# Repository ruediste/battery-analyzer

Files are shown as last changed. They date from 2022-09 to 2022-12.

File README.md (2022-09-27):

# battery-analyzer
Open Source battery analyzer

# Resistor Matching
When building your channel boards, make sure to match the resistors. See `firmware/src/resistorMatcher.cpp` for details.

# Calibration

1. Calibrate Voltage: connect a PSU to the plus pole of the battery, apply about 4.2V. Measure the voltage and enter it.
1. Zero PWM:

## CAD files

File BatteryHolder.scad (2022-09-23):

// Distance between the cell centers. 35mm allow you to easily grab the cells.
period=35;

// Diameter of the battery
batteryDiameter=18;

// number of holder units
units=4;

// add slides for the battery plate/slide 
plateSlide=false;

// add a hole to use a screw to connect to the battery terminals
screw=false;

/* Hidden */
$fn=10;
module mountingUnit(){
    //translate([0,0,0]) rotate([-90,0,0]) cylinder(h=65.0,d=18);
    translate([0,-5,0]) difference() {
        union(){
            translate([0,-25/2,0]) cube([period+2.51,25,20], center=true);
            
            // plateSlide holder
            if (plateSlide) translate([0,0.99,0]) cube([14.5,2,20], center=true);
        }
        
        translate([0,-30.01/2,2]) cube([period-2.5,20,20], center=true);
        
        if (screw){
        // hex
        translate([0,-3,0]) rotate([-90,0,0]) cylinder(h=4, d=6.35, $fn=6);
        
        // screw hole
        translate([0,-6,0]) rotate([-90,0,0]) cylinder(h=7, d=3.5);
        
        // wire hole
        translate([period/2-4,-6,0]) rotate([-90,0,0]) cylinder(h=7, d=3.5);
               
        // wire opening
        translate([period/4-2,0.5,0]) cube([period/2,3,3.5], center=true);
        }
        
        // 45 deg sides
        translate([0,-22,10]) rotate([45,0,0]) cube([period+7,40,20], center=true);
        
        // mounting slot
        translate([0,-18,-15]) rotate([0,0,0]) cylinder(h=20, d=5);
        translate([0,-12,-15]) rotate([0,0,0]) cylinder(h=20, d=5);
        translate([-2.5,-18,-15]) cube([5,6,10]);
        
        if (plateSlide){
            // plateSlide slide
            translate([0,0.49,4.5-10]) cube([10.5,1,20], center=true);
            
            // plateSlide middle
            translate([0,1.49,0]) cube([7.5,3,25], center=true);
        } else {
            // plateSlide position
            if (!screw) translate([0,0,1]) cube([11,1,12], center=true);
        }
        
        // plateSlide lead
        translate([0,-4,14.5]) cube([4,10,20], center=true);
        
        // reduce height
        translate([-period/2-5,-15,5.5]) cube([period+10,20,20]);

    }
}
for (i=[1:units]){
    translate([(period)*(i-1),0,0])    mountingUnit();
}

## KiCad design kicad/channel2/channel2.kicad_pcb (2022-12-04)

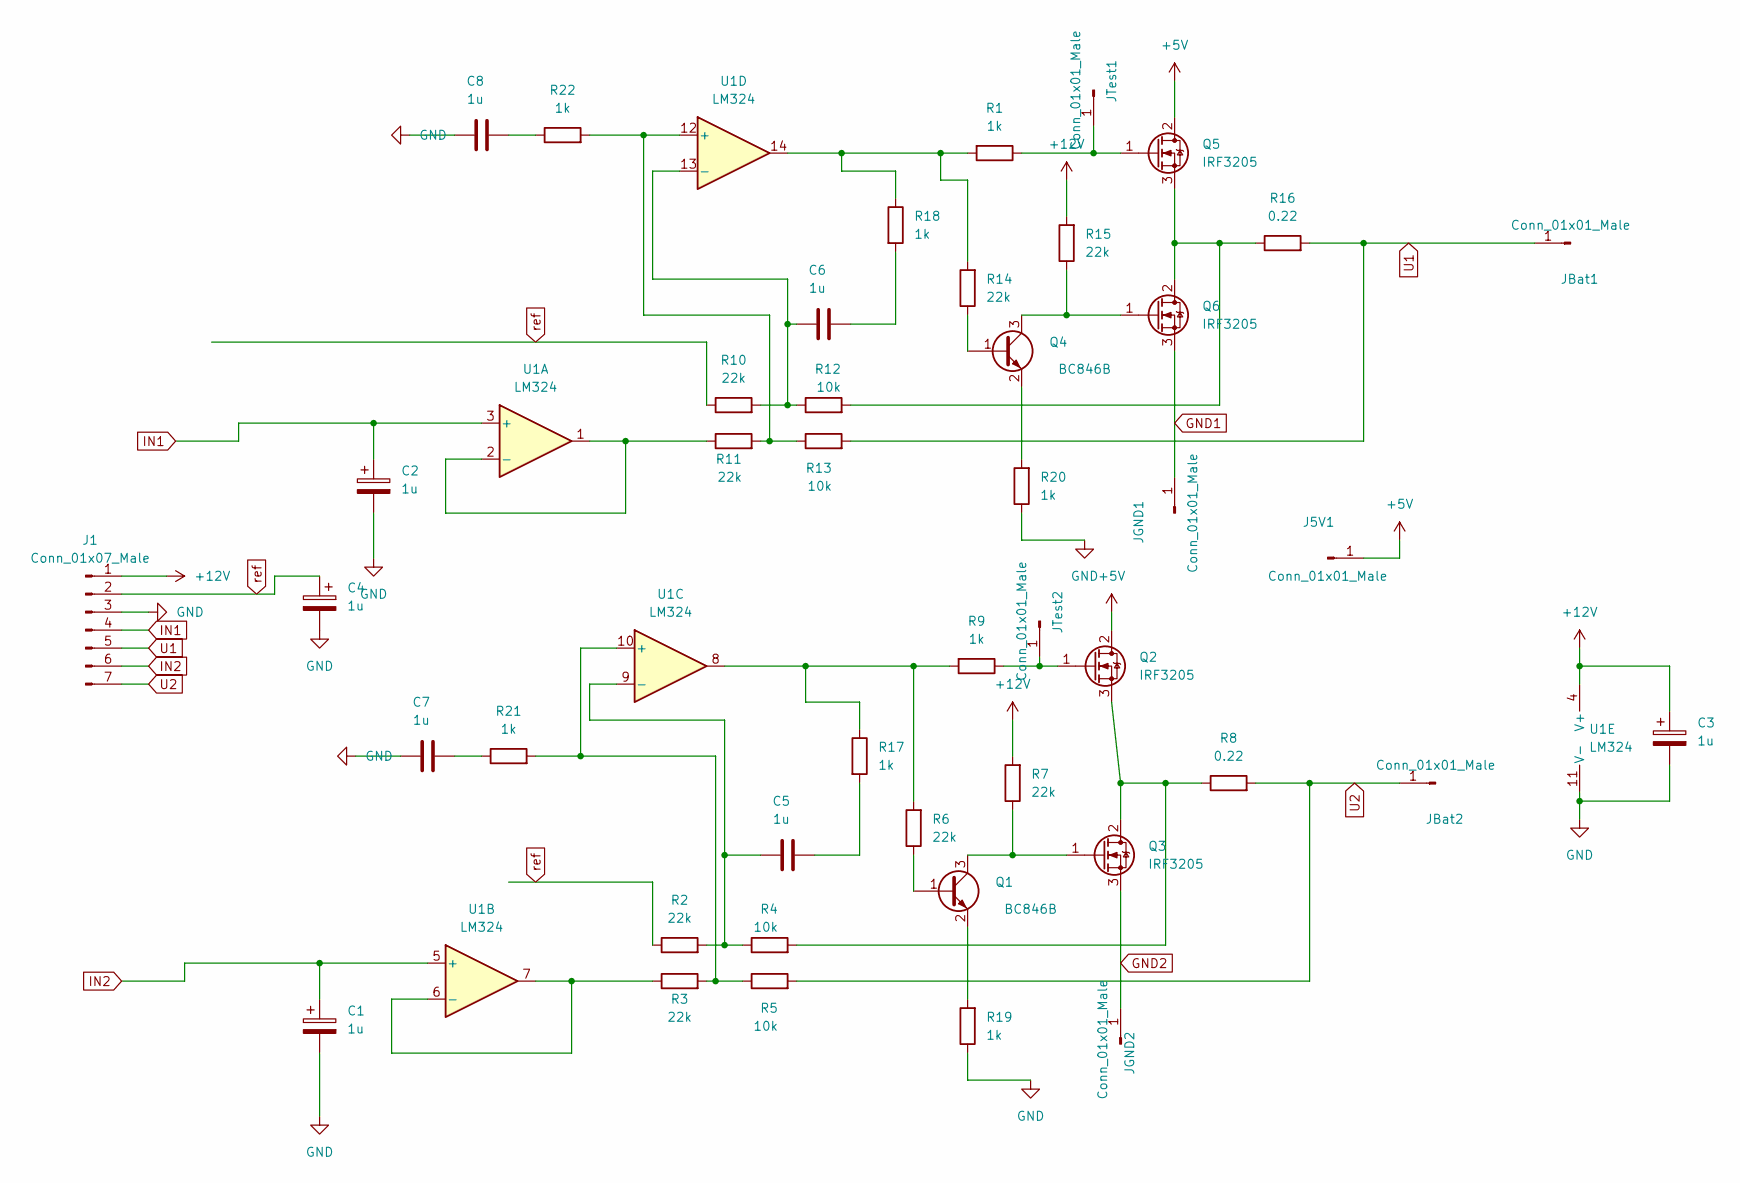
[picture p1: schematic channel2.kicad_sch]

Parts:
C1, C2, C3, C4, C5, C6, C7, C8: 1u; C_0603_1608Metric
J1: Conn_01x07_Male; PinHeader_1x07_P2.54mm_Vertical
J5V1: Conn_01x01_Male; PowerPad
JBat1, JBat2: Conn_01x01_Male; PowerPad
JGND1, JGND2: Conn_01x01_Male; PowerPad
JTest1, JTest2: Conn_01x01_Male; PinHeader_1x01_P2.54mm_Vertical
Q1, Q4: BC846B; SOT-23
Q2, Q3, Q5, Q6: IRF3205; TO-220-3_Vertical
R1, R9, R17, R18, R19, R20, R21, R22: 1k; R_1206_3216Metric
R2, R3, R6, R7, R10, R11, R14, R15: 22k; R_1206_3216Metric
R4, R5, R12, R13: 10k; R_1206_3216Metric
R8, R16: 0.22; R_Axial_DIN0617_L17.0mm_D6.0mm_P25.40mm_Horizontal
U1: LM324; SOIC-14_3.9x8.7mm_P1.27mm

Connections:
+5V: J5V1.1, Q2.2 (D), Q5.2 (D)
+12V: C3.1, J1.1, R7.2, R15.2, U1.4 (V+)
GND: C1.2, C2.2, C3.2, C4.2, C7.1, C8.1, J1.3, R19.1, R20.1, U1.11 (V-)
GND1: JGND1.1, Q6.3 (S)
GND2: JGND2.1, Q3.3 (S)
IN1: C2.1, J1.4, U1.3 (+)
IN2: C1.1, J1.6, U1.5 (+)
unnamed: C5.1, R2.2, R4.1, U1.9 (-)
unnamed: C5.2, R17.2
unnamed: C6.1, R10.2, R12.1, U1.13 (-)
unnamed: C6.2, R18.2
unnamed: C7.2, R21.1
unnamed: C8.2, R22.1
unnamed: JTest1.1, Q5.1 (G), R1.1
unnamed: JTest2.1, Q2.1 (G), R9.1
unnamed: Q1.1 (B), R6.1
unnamed: Q1.2 (E), R19.2
unnamed: Q1.3 (C), Q3.1 (G), R7.1
unnamed: Q2.3 (S), Q3.2 (D), R4.2, R8.1
unnamed: Q4.1 (B), R14.1
unnamed: Q4.2 (E), R20.2
unnamed: Q4.3 (C), Q6.1 (G), R15.1
unnamed: Q5.3 (S), Q6.2 (D), R12.2, R16.1
unnamed: R1.2, R14.2, R18.1, U1.14
unnamed: R3.1, U1.6 (-), U1.7
unnamed: R11.1, U1.1, U1.2 (-)
unnamed: R11.2, R13.1, R22.2, U1.12 (+)
unnamed: R6.2, R9.2, R17.1, U1.8
unnamed: R3.2, R5.1, R21.2, U1.10 (+)
U1: J1.5, JBat1.1, R13.2, R16.2
U2: J1.7, JBat2.1, R5.2, R8.2
ref: C4.1, J1.2, R2.1, R10.1

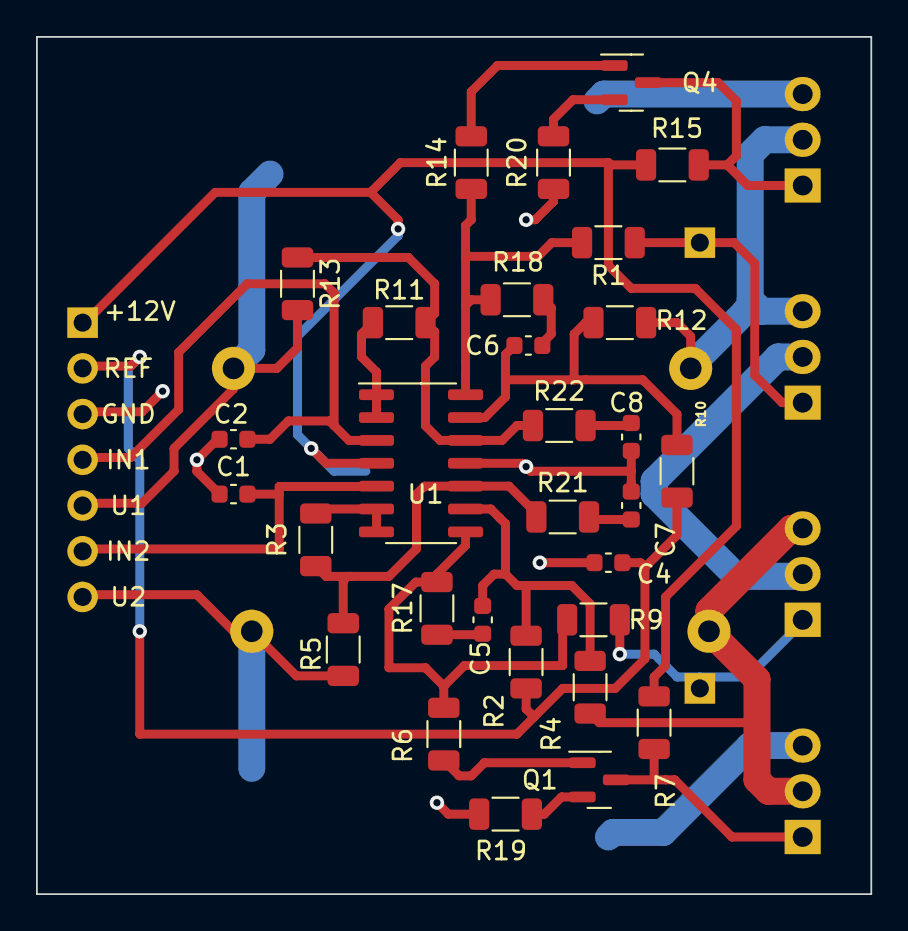
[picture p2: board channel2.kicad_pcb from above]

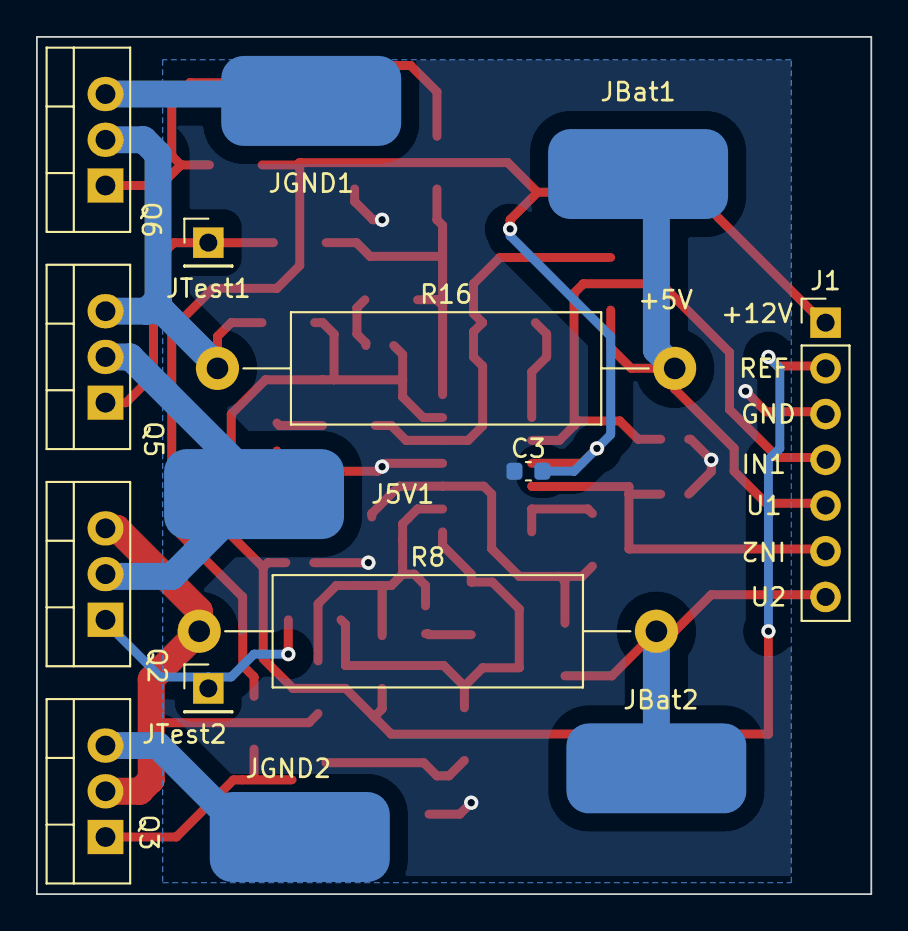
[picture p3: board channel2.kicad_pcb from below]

Board: 2 copper layers, 46.4 x 47.6 mm, 45 parts (15 on the bottom side), 32 nets.

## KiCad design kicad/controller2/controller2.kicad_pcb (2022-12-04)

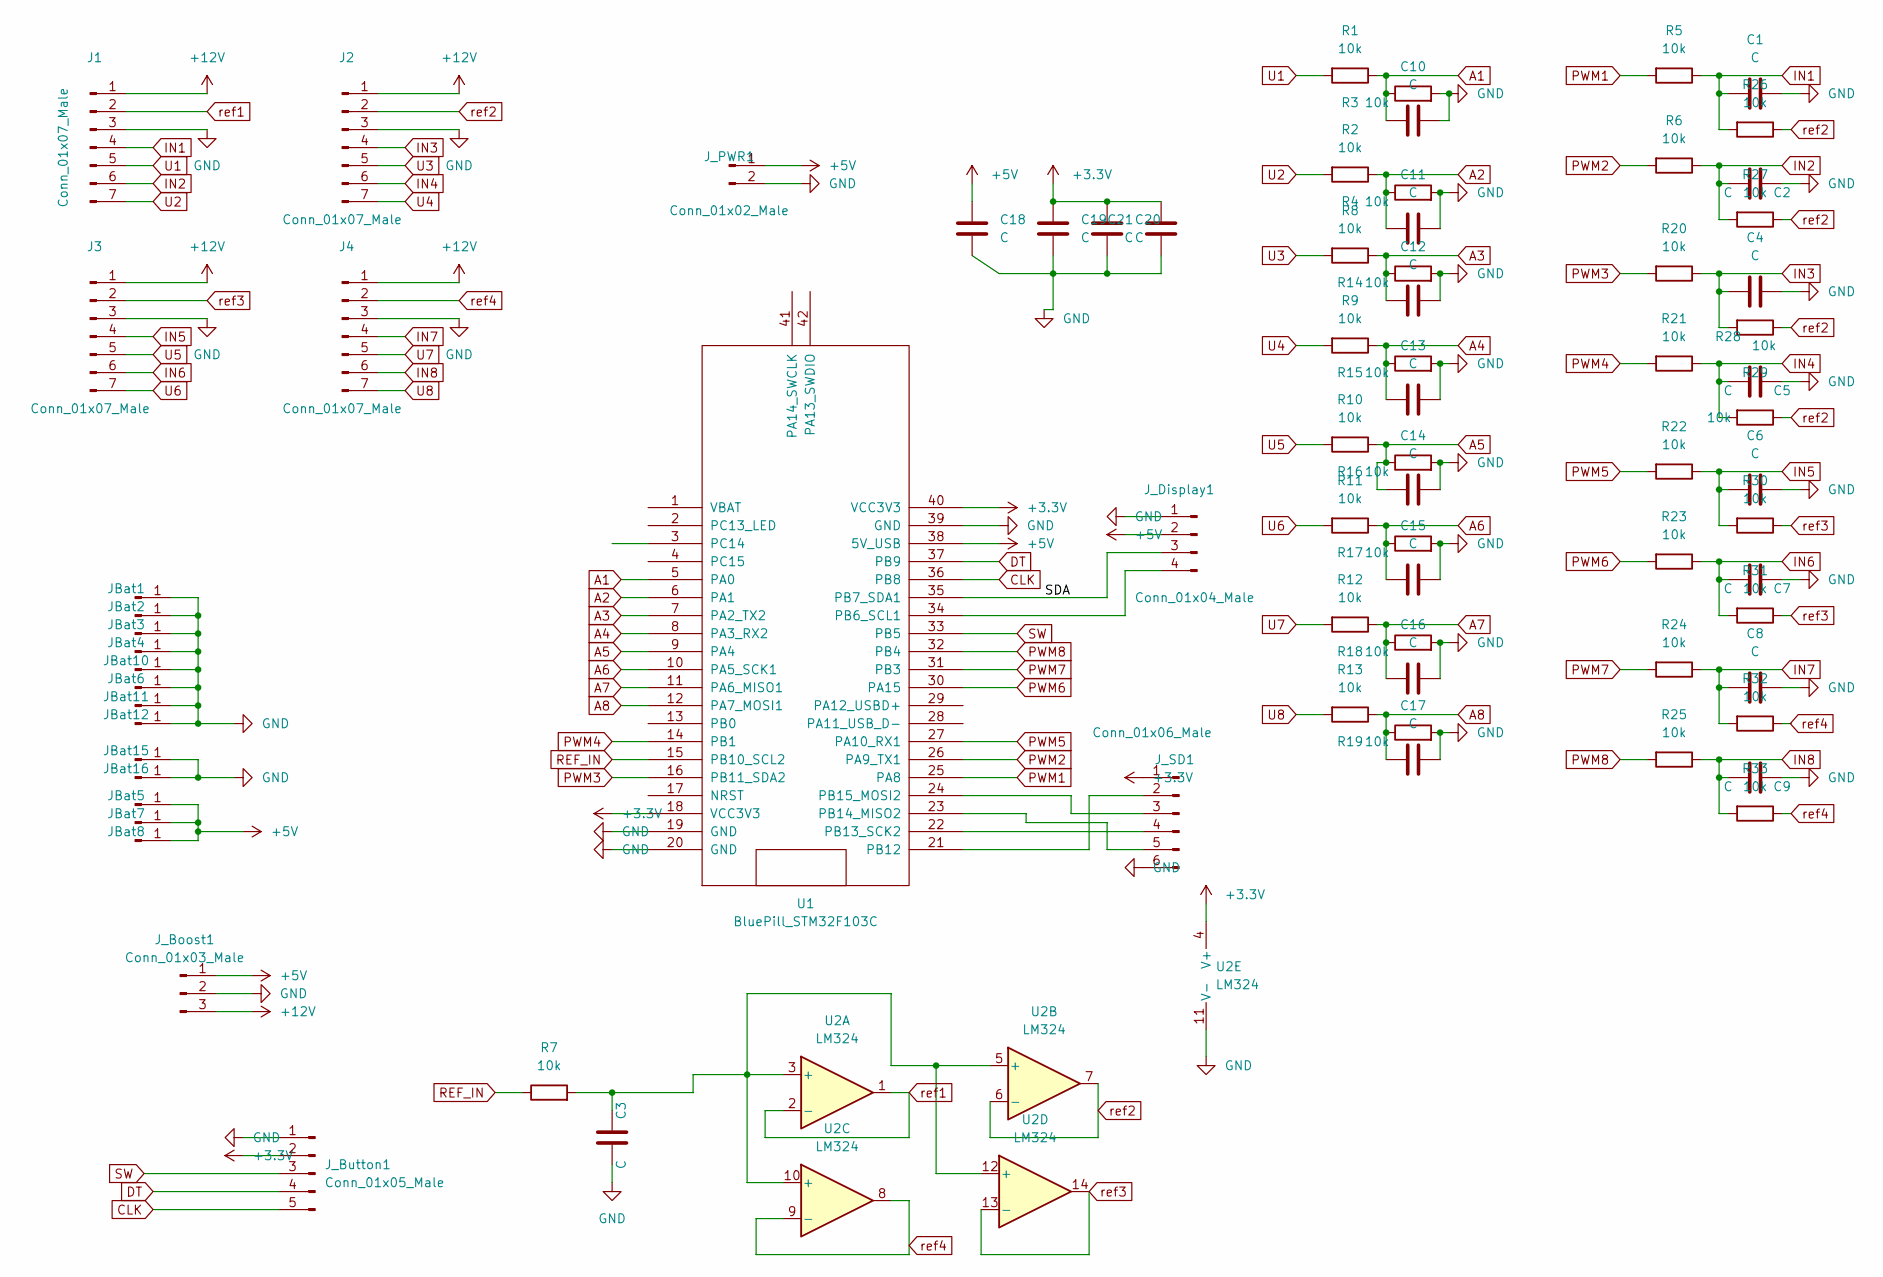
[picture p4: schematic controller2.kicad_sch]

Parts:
C1, C2, C3, C4, C5, C6, C7, C8, C9, C10, C11, C12, C13, C14, C15, C16, C17, C18, C19, C20, C21: C; C_0805_2012Metric
J1, J2, J3, J4: Conn_01x07_Male; PinHeader_1x07_P2.54mm_Vertical
JBat1, JBat2, JBat3, JBat4, JBat5, JBat6, JBat7, JBat8, JBat10, JBat11, JBat12, JBat15, JBat16: Conn_01x01_Male; PowerPin
J_Boost1: Conn_01x03_Male; PinHeader_1x03_P2.54mm_Vertical
J_Button1: Conn_01x05_Male; PinHeader_1x05_P2.54mm_Vertical
J_Display1: Conn_01x04_Male; PinHeader_1x04_P2.54mm_Vertical
J_PWR1: Conn_01x02_Male; PinHeader_1x02_P2.54mm_Vertical
J_SD1: Conn_01x06_Male; SD_Card_reader
R1, R2, R3, R4, R5, R6, R7, R8, R9, R10, R11, R12, R13, R14, R15, R16, R17, R18, R19, R20, R21, R22, R23, R24, R25, R26, R27, R28, R29, R30, R31, R32, R33: 10k; R_1206_3216Metric
U1: BluePill_STM32F103C; BluePill
U2: LM324; SOIC-14_3.9x8.7mm_P1.27mm

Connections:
+3.3V: C19.2, C20.2, C21.2, J_Button1.2, J_SD1.1, U1.18 (VCC3V3), U1.40 (VCC3V3), U2.4 (V+)
+5V: C18.2, JBat5.1, JBat7.1, JBat8.1, J_Boost1.1, J_Display1.2, J_PWR1.1, U1.38 (5V_USB)
+12V: J1.1, J2.1, J3.1, J4.1, J_Boost1.3
/SDA: J_Display1.3, U1.35 (PB7_SDA1)
A1: C10.1, R1.1, R3.1, U1.5 (PA0)
A2: C11.1, R2.1, R4.1, U1.6 (PA1)
A3: C12.1, R8.1, R14.1, U1.7 (PA2_TX2)
A4: C13.1, R9.1, R15.1, U1.8 (PA3_RX2)
A5: C14.1, R10.1, R16.1, U1.9 (PA4)
A6: C15.1, R11.1, R17.1, U1.10 (PA5_SCK1)
A7: C16.1, R12.1, R18.1, U1.11 (PA6_MISO1)
A8: C17.1, R13.1, R19.1, U1.12 (PA7_MOSI1)
CLK: J_Button1.5, U1.36 (PB8)
DT: J_Button1.4, U1.37 (PB9)
GND: C1.2, C2.2, C3.1, C4.2, C5.2, C6.2, C7.2, C8.2, C9.2, C10.2, C11.2, C12.2, C13.2, C14.2, C15.2, C16.2, C17.2, C18.1, C19.1, C20.1, C21.1, J1.3, J2.3, J3.3, J4.3, JBat1.1, JBat2.1, JBat3.1, JBat4.1, JBat6.1, JBat10.1, JBat11.1, JBat12.1, JBat15.1, JBat16.1, J_Boost1.2, J_Button1.1, J_Display1.1, J_PWR1.2, J_SD1.6, R3.2, R4.2, R14.2, R15.2, R16.2, R17.2, R18.2, R19.2, U1.19 (GND), U1.20 (GND), U1.39 (GND), U2.11 (V-)
IN1: C1.1, J1.4, R5.1, R26.2
IN2: C2.1, J1.6, R6.1, R27.2
IN3: C4.1, J2.4, R20.1, R28.2
IN4: C5.1, J2.6, R21.1, R29.2
IN5: C6.1, J3.4, R22.1, R30.2
IN6: C7.1, J3.6, R23.1, R31.2
IN7: C8.1, J4.4, R24.1, R32.2
IN8: C9.1, J4.6, R25.1, R33.2
unnamed: C3.2, R7.2, U2.3 (+), U2.5 (+), U2.10 (+), U2.12 (+)
unnamed: J_Display1.4, U1.34 (PB6_SCL1)
unnamed: J_SD1.2, U1.21 (PB12)
unnamed: J_SD1.3, U1.24 (PB15_MOSI2)
unnamed: J_SD1.4, U1.22 (PB13_SCK2)
unnamed: J_SD1.5, U1.23 (PB14_MISO2)
PWM1: R5.2, U1.25 (PA8)
PWM2: R6.2, U1.26 (PA9_TX1)
PWM3: R20.2, U1.16 (PB11_SDA2)
PWM4: R21.2, U1.14 (PB1)
PWM5: R22.2, U1.27 (PA10_RX1)
PWM6: R23.2, U1.30 (PA15)
PWM7: R24.2, U1.31 (PB3)
PWM8: R25.2, U1.32 (PB4)
REF_IN: R7.1, U1.15 (PB10_SCL2)
SW: J_Button1.3, U1.33 (PB5)
U1: J1.5, R1.2
U2: J1.7, R2.2
U3: J2.5, R8.2
U4: J2.7, R9.2
U5: J3.5, R10.2
U6: J3.7, R11.2
U7: J4.5, R12.2
U8: J4.7, R13.2
ref1: J1.2, U2.1, U2.2 (-)
ref2: J2.2, R26.1, R27.1, R28.1, R29.1, U2.6 (-), U2.7
ref3: J3.2, R30.1, R31.1, U2.13 (-), U2.14
ref4: J4.2, R32.1, R33.1, U2.8, U2.9 (-)

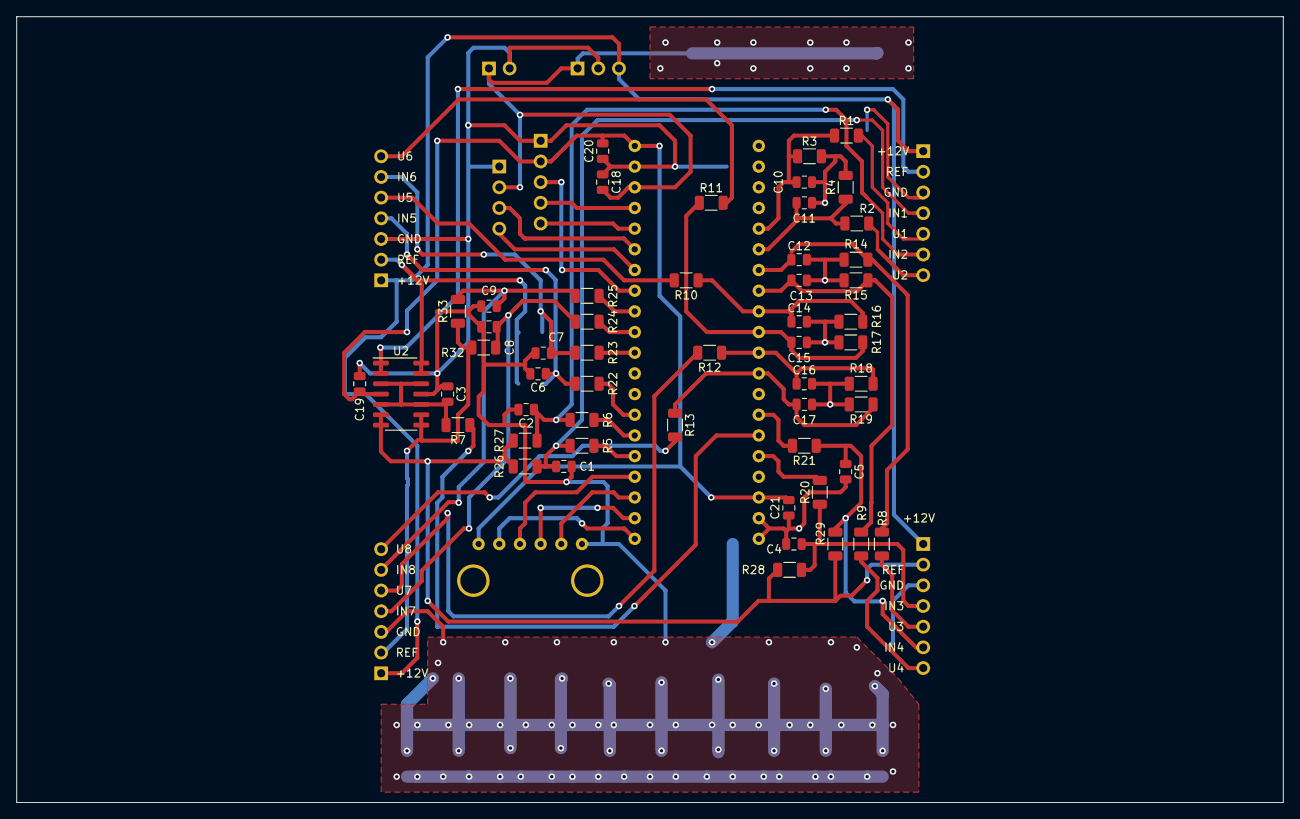
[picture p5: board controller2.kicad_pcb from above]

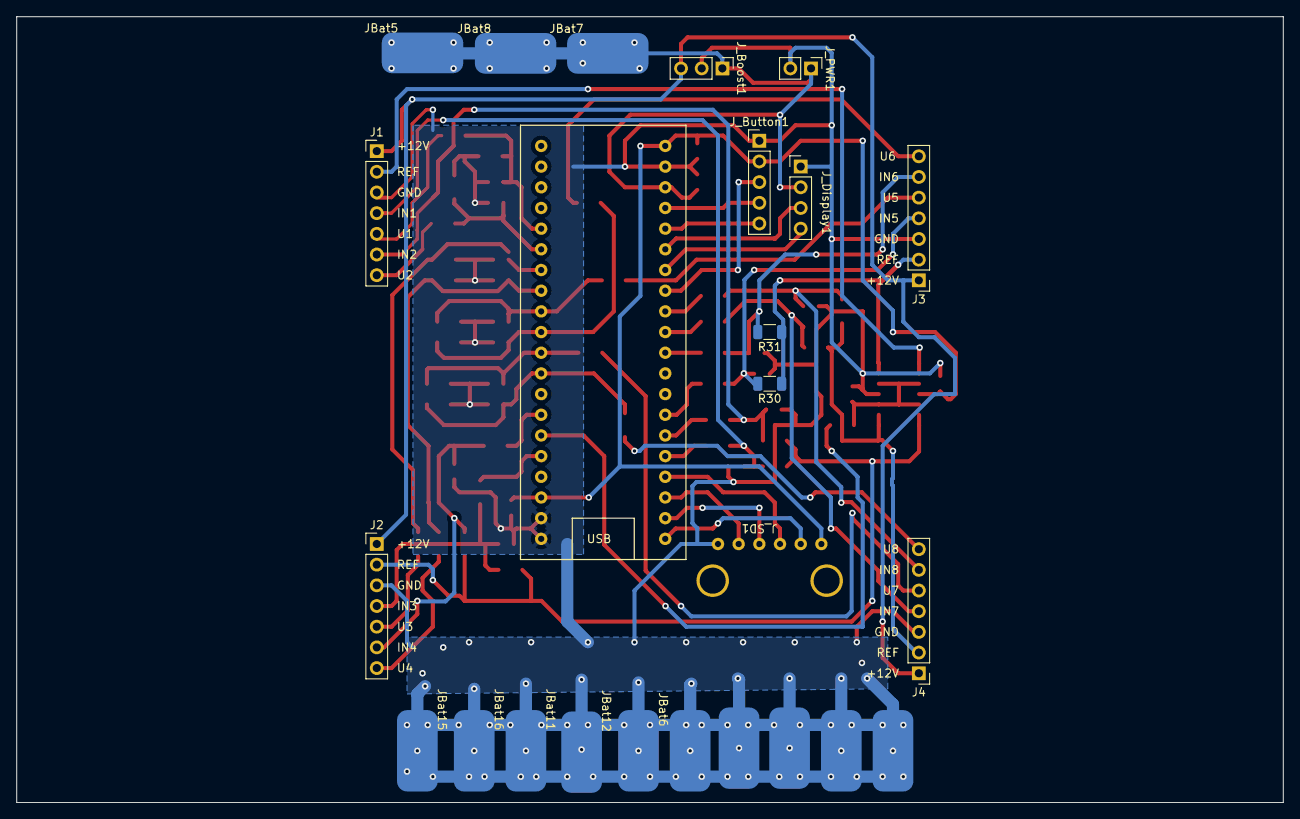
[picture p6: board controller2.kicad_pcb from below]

Board: 2 copper layers, 155.6 x 96.5 mm, 78 parts (25 on the bottom side), 51 nets.

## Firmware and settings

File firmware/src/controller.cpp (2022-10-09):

#include "controller.h"
#include "menu.h"
#include "display.h"
#include "types.h"
#include "input.h"
#include "batteryChannel.h"
#include "utils.h"
#include "numberInput.h"
#include "eeprom.h"
#include "sdLogging.h"
#include "messageDisplay.h"
#include "log.h"

namespace controller
{
    int _currentChannel = 0;

    bool showStatistics = false;
    int statisticsPage = 0;
    int maxStatisticsPage = 1;

    instantMs_t lastDisplayUpdate = 0;

    BatteryChannel &currentChannel()
    {
        return BatteryChannel::channels[_currentChannel];
    }
    eeprom::ChannelSetup &currentChannelSetup()
    {
        // return eeprom::data.channelSetup[_currentChannel];
        return currentChannel().setup();
    }

    eeprom::ChannelConfig &currentChannelConfig()
    {
        return currentChannel().config();
    }

    void printTime(float timeSeconds)
    {
        int minutes = (int)(timeSeconds / 60);
        display::print(minutes);
        display::print(F(":"));
        display::print(timeSeconds - minutes * 60);
    }

    void printStatistics(eeprom::Statistics &stats)
    {
        display::setCursor(0, 1);
        display::print(stats.milliAmperHours());
        display::print(F(" mAh"));

        display::setCursor(0, 2);
        display::print(stats.wattHours(), 3);
        display::print(F(" Wh"));

        display::setCursor(0, 3);
        display::print(F("Time "));
        printTime(stats.seconds);
    }

    void printTestSummary()
    {
        eeprom::ChannelSetup &c = currentChannelSetup();

        display::setCursor(0, 1);
        display::print(F("Eff "));
        display::print(c.efficiencyPercent());
        display::print(F("%"));

        display::setCursor(0, 2);
        display::print(F("Cap "));
        display::print((abs(c.stats.milliAmperHours()) + abs(c.dischargeStats.milliAmperHours())) / 2., 0);
        display::print(F(" mAh "));
        display::print(c.capacityDifferencePercent(), 1);
        display::print(F("%"));

        display::setCursor(0, 3);
        display::print((abs(c.stats.wattHours()) + abs(c.dischargeStats.wattHours())) / 2, 3);
        display::print(F(" Wh"));
    }

    void updateDisplay()
    {
        lastDisplayUpdate = utils::now();

        display::clear();
        display::setCursor(0, 0);

        display::print(F("CH: "));

        display::print(_currentChannel);
        display::print(F(" "));

        if (showStatistics)
        {
            int page = 0;
            bool testRunning = currentChannelSetup().mode == eeprom::ChannelMode::Charger && currentChannelSetup().chargeMode == eeprom::ChargeMode::Test;
            if (currentChannelSetup().mode == eeprom::ChannelMode::Charger)
            {

                if (statisticsPage == page++)
                {
                    display::print(F("Stats"));
                    printStatistics(currentChannelSetup().stats);
                }

                if (currentChannel().dischargeStatsPresent())
                {
                    if (statisticsPage == page++)
                    {
                        display::print(F("Stats Dis"));
                        printStatistics(currentChannelSetup().dischargeStats);
                    }
                }

                if (currentChannel().completeStatsPresent())
                {
                    if (statisticsPage == page++)
                    {
                        display::print(F("Stats Summary"));
                        printTestSummary();
                    }
                }
                maxStatisticsPage = page;
                if (statisticsPage >= maxStatisticsPage)
                {
                    statisticsPage = maxStatisticsPage - 1;
                }
            }
            else
            {
                printStatistics(currentChannelSetup().stats);
            }
            return;
        }

        switch (currentChannelSetup().mode)
        {
        case eeprom::ChannelMode::Charger:
            switch (currentChannelSetup().chargeMode)
            {
            case eeprom::ChargeMode::Charge:
                display::print(F("Charging"));
                break;
            case eeprom::ChargeMode::Discharge:
                display::print(F("Discharging"));
                ;
                break;
            case eeprom::ChargeMode::Idle:
                display::print(F("Idle"));
                break;

            case eeprom::ChargeMode::Test:
                switch (currentChannel().testState())
                {
                case TestController::State::PreCharge:
                    display::print(F("Pre Charge"));
                    break;
                case TestController::State::PreDischarge:
                    display::print(F("Pre Discharge"));
                    break;
                case TestController::State::MainCharge:
                    display::print(F("Main Charge"));
                    break;
                case TestController::State::MainDischarge:
                    display::print(F("Main Discharge"));
                    break;
                }
                break;
            }
            break;
        case eeprom::ChannelMode::CV_CC_Source:
            display::print(F("CV CC Src"));
            break;
        case eeprom::ChannelMode::CV_CC_Sink:
            display::print(F("CV CC Sink"));
            break;
        case eeprom::ChannelMode::Resistor_Source:
            display::print(F("Res Source"));
            break;
        case eeprom::ChannelMode::Resistor_Sink:
            display::print(F("Res Sink"));
            break;
        case eeprom::ChannelMode::Power_Source:
            display::print(F("Power Source"));
            break;
        case eeprom::ChannelMode::Power_Sink:
            display::print(F("Power Sink"));
            break;
        case eeprom::ChannelMode::Direct_PWM:
            display::print(F("Direct PWM"));
            break;
        }

        if (currentChannelSetup().mode == eeprom::ChannelMode::Charger && currentChannel().completeStatsPresent())
        {
            printTestSummary();
            return;
        }
        BatteryChannel &c = BatteryChannel::channels[_currentChannel];
        display::setCursor(0, 1);
        display::print(c.batteryVoltage());
        display::print(F(" V "));
        display::print(c.effectiveCurrent());
        display::print(F(" A "));

        display::setCursor(0, 2);
        display::print(currentChannelSetup().stats.milliAmperHours());
        display::print(F(" mAh"));

        if (currentChannelSetup().mode == eeprom::ChannelMode::Direct_PWM)
        {
            display::setCursor(0, 3);
            display::print(F("PWM "));
            display::print(currentChannel().control.outputCurrentPWM);
        }
        else
        {
            display::setCursor(0, 3);
            display::print(F("Time "));
            printTime(currentChannelSetup().stats.seconds);
        }
    }

    void enterChannelMenu();
    void enterChannelConfigMenu();
    void enterGlobalConfigMenu();

    void (*modeMenuChosenCallback)(eeprom::ChannelMode mode);
    void (*modeMenuBackCallback)();

    struct ModeMenu : public menu::MenuHandler
    {

        void handleMenu(uint8_t i, bool print) override
        {
            switch (i)
            {
            case 0:
                if (print)
                    display::print(F("Charger"));
                else
                {
                    modeMenuChosenCallback(eeprom::ChannelMode::Charger);
                }
                break;
            case 1:
                if (print)
                    display::print(F("CVCC Source"));
                else
                {
                    modeMenuChosenCallback(eeprom::ChannelMode::CV_CC_Source);
                }
                break;
            case 2:
                if (print)
                    display::print(F("Direct PWM"));
                else
                {
                    modeMenuChosenCallback(eeprom::ChannelMode::Direct_PWM);
                }
                break;
            case 3:
                if (print)
                    display::print(F("CVCC Sink"));
                else
                {
                    modeMenuChosenCallback(eeprom::ChannelMode::CV_CC_Sink);
                }
                break;
            case 4:
                if (print)
                    display::print(F("Resistor Source"));
                else
                {
                    modeMenuChosenCallback(eeprom::ChannelMode::Resistor_Source);
                }
                break;
            case 5:
                if (print)
                    display::print(F("Resistor Sink"));
                else
                {
                    modeMenuChosenCallback(eeprom::ChannelMode::Resistor_Sink);
                }
                break;
            case 6:
                if (print)
                    display::print(F("Power Source"));
                else
                {
                    modeMenuChosenCallback(eeprom::ChannelMode::Power_Source);
                }
                break;
            case 7:
                if (print)
                    display::print(F("Power Sink"));
                else
                {
                    modeMenuChosenCallback(eeprom::ChannelMode::Power_Sink);
                }
                break;

            case 8:
                if (print)
                    display::print(F("..."));
                else
                {
                    modeMenuBackCallback();
                }
                break;
            }
        }

        uint8_t menuItemCount() override
        {
            return 9;
        }
    };

    ModeMenu modeMenu;

    struct GlobalConfigMenu : public menu::MenuHandler
    {

        void handleMenu(uint8_t i, bool print) override
        {
            switch (i)
            {
            case 0:
                if (print)
                    display::print(F("Charge Voltage"));
                else
                {
                    menu::leave();
                    numberInput::enter(
                        eeprom::data.chargeVoltage * 100, 2, 2, [](auto &c)
                        {
                        c.success = [](uint32_t value)
                        {
                            eeprom::data.chargeVoltage=value/100.;
                            eeprom::flush();
                            enterGlobalConfigMenu(); 
                        };
                        c.cancel =[]{enterGlobalConfigMenu(); }; });
                }
                break;
            case 1:
                if (print)
                    display::print(F("Charge Current"));
                else
                {
                    menu::leave();
                    numberInput::enter(
                        eeprom::data.chargeCurrent * 100, 2, 2, [](auto &c)
                        {
                        c.success = [](uint32_t value)
                        {
                            eeprom::data.chargeCurrent=value/100.;
                            eeprom::flush();
                            enterGlobalConfigMenu(); 
                        };
                        c.cancel =[]{enterGlobalConfigMenu(); }; });
                }
                break;
            case 2:
                if (print)
                    display::print(F("Ch Cutoff Current"));
                else
                {
                    menu::leave();
                    numberInput::enter(
                        eeprom::data.chargeCutoffCurrent * 100, 2, 2, [](auto &c)
                        {
                        c.success = [](uint32_t value)
                        {
                            eeprom::data.chargeCutoffCurrent=value/100.;
                            eeprom::flush();
                            enterGlobalConfigMenu(); 
                        };
                        c.cancel =[]{enterGlobalConfigMenu(); }; });
                }
                break;
            case 3:
                if (print)
                    display::print(F("Discharge Voltage"));
                else
                {
                    menu::leave();
                    numberInput::enter(
                        eeprom::data.dischargeVoltage * 100, 2, 2, [](auto &c)
                        {
                        c.success = [](uint32_t value)
                        {
                            eeprom::data.dischargeVoltage=value/100.;
                            eeprom::flush();
                            enterGlobalConfigMenu(); 
                        };
                        c.cancel =[]{enterGlobalConfigMenu(); }; });
                }
                break;
            case 4:
                if (print)
                    display::print(F("Discharge Current"));
                else
                {
                    menu::leave();
                    numberInput::enter(
                        eeprom::data.dischargeCurrent * 100, 2, 2, [](auto &c)
                        {
                        c.success = [](uint32_t value)
                        {
                            eeprom::data.dischargeCurrent=value/100.;
                            eeprom::flush();
                            enterGlobalConfigMenu(); 
                        };
                        c.cancel = enterGlobalConfigMenu; });
                }
                break;
            case 5:
                if (print)
                    display::print(F("Dis Cutoff Current"));
                else
                {
                    menu::leave();
                    numberInput::enter(
                        eeprom::data.dischargeCutoffCurrent * 100, 2, 2, [](auto &c)
                        {
                        c.success = [](uint32_t value)
                        {
                            eeprom::data.dischargeCutoffCurrent=value/100.;
                            eeprom::flush();
                            enterGlobalConfigMenu(); 
                        };
                        c.cancel = enterGlobalConfigMenu; });
                }
                break;
            case 6:
                if (print)
                {
                    display::print(F("Startup Ch Mode"));
                }
                else
                {
                    modeMenuChosenCallback = [](eeprom::ChannelMode mode)
                    {
                        eeprom::data.startupChannelMode = mode;
                        eeprom::flush();
                        enterGlobalConfigMenu();
                    };
                    modeMenuBackCallback = enterGlobalConfigMenu;
                    menu::enter(modeMenu);
                }
                break;
            case 7:
                if (print)
                    display::print("Reset EEPROM");
                else
                {
                    menu::leave();
                    messageDisplay::show(
                        "Reset EEPROM?", []()
                        {
                        eeprom::data = eeprom::Data();
                        eeprom::flush();
                        messageDisplay::show("Reset Complete",[](){}); },
                        []() {});
                }
                break;
            case 8:
                if (print)
                    display::print(F("..."));
                else
                {
                    enterChannelMenu();
                }
                break;
            }
        }

        uint8_t menuItemCount() override
        {
            return 9;
        }
    };

    GlobalConfigMenu globalConfigMenu;
    void enterGlobalConfigMenu()
    {
        menu::enter(globalConfigMenu);
    }
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
    void loop()
    {
        input::loop();
        menu::loop();
        numberInput::loop();
        sdLogging::loop();
        messageDisplay::loop();

        for (int i = 0; i < channelCount; i++)
        {
            BatteryChannel::channels[i].loop();
        }

        if (menu::active() || numberInput::active() || messageDisplay::active())
            return;

        if (utils::now() > lastDisplayUpdate + 500)
        {
            updateDisplay();
        }

        if (showStatistics)
        {
            int move = input::getAndResetInputEncoder();
            if (move != 0)
            {
                statisticsPage += move;
                if (statisticsPage < 0)
                {
                    statisticsPage = 0;
                }
                if (statisticsPage >= maxStatisticsPage)
                {
                    statisticsPage = maxStatisticsPage - 1;
                }
                updateDisplay();
            }
            if (input::getAndResetInputEncoderClicked())
            {
                showStatistics = false;
            }
            return;
        }

        int move = input::getAndResetInputEncoder();
        if (move != 0)
        {
            _currentChannel += move;
            if (_currentChannel < 0)
                _currentChannel = 0;
            if (_currentChannel >= channelCount)
                _currentChannel = channelCount - 1;
            updateDisplay();
        }
        if (input::getAndResetInputEncoderClicked())
        {
            // enterGlobalConfigMenu();
            enterChannelMenu();
        }
    }
}

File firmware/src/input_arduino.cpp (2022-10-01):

#define INPUT_CPP
#include "config.h"

#if IS_FRAMEWORK_ARDUINO
#include <Arduino.h>
#include "input.h"
#include "utils.h"

namespace input
{
  static utils::Protected<bool> inputEncoderPressed = false;
  static volatile unsigned long lastEncoderPressedChangedMs;
  bool lastInputEncoderPressed = false;

  void processInputs();

  void init()
  {
    lastEncoderPressedChangedMs = 0;
#ifdef IS_AVR
    /*
      For our application we use the pin change interrupt on PortD
      Input Encoder: 4x with pins PortD2(D2) and PortD3(D3)
      Input Encoder Switch: PortD4(D4)
    */

    // setup pin change interrupt
    PORTD = 0b11100;      // enable soft pull up on PortD2-D4
    PCICR = (1 << PCIE2); // enable pin change interrupt 1 (PCINT 16..28)
    PCMSK2 = 0b11100;     // enable PortD2-D4 for interrupts
#endif

#ifdef IS_STM
    /*
    For our application we use the pin change interrupt on Port B
    Input Encoder: 4x with pins PortB12(B12) and PortB13(B13)
    Input Encoder Switch: PortV14(B14)
  */

    // // setup pin change interrupt
    // AFIO->EXTICR[2] = (AFIO->EXTICR[2] & ~0xFFF) | 0x111; // set pb for EXTI12-EXTI14
    // EXTI->RTSR |= 0b111 < 12;                             // rising trigger mask
    // EXTI->FTSR |= 0b111 < 12;                             // falling trigger mask
    // EXTI->IMR |= 0b111 < 12;                              // interrupt mask

    pinMode(PB5, INPUT_PULLDOWN);
    pinMode(PB8, INPUT_PULLDOWN);
    pinMode(PB9, INPUT_PULLDOWN);
    attachInterrupt(digitalPinToInterrupt(PB5), processInputs, CHANGE);
    attachInterrupt(digitalPinToInterrupt(PB8), processInputs, CHANGE);
    attachInterrupt(digitalPinToInterrupt(PB9), processInputs, CHANGE);
#endif
  }

  void loop()
  {
    // debounce input encoder pressing
    bool newValue = inputEncoderPressed;
    if (newValue != lastInputEncoderPressed)
    {
      unsigned long now = millis();
      unsigned long duration = now - lastEncoderPressedChangedMs;
      if (duration > 100)
      {
        if (newValue)
          inputEncoderClicked = true;
        lastInputEncoderPressed = newValue;
        lastEncoderPressedChangedMs = now;
      }
    }
  }

  /*
   * 00
   * 01
   * 11
   * 10
   * 00
   */
  int8_t getMovement4x(int8_t oldBits, int8_t newBits)
  {
    switch (oldBits << 2 | newBits)
    {
    case 0b0001:
    case 0b0111:
    case 0b1110:
    case 0b1000:
      return 1;
    case 0b0010:
    case 0b1011:
    case 0b1101:
    case 0b0100:
      return -1;
    default:
      return 0;
    }
  }

  int8_t countInputEncoderInternal;
  uint8_t oldBits;

  void processInputs()
  {
    uint8_t newBits = GPIOB->IDR >> 8;
    int8_t tmp = getMovement4x((oldBits)&0b11, (newBits)&0b11);
    if (tmp != 0)
    {
      countInputEncoderInternal += tmp;
      if ((newBits & 0b11) == 0b11) // 11 is the settle state
      {                             // we reached the settle state
        if (countInputEncoderInternal != 0)
          inputEncoderCount.direct() += countInputEncoderInternal > 0 ? 1 : -1;
        countInputEncoderInternal = 0;
      }
    }
    inputEncoderPressed = (GPIOB->IDR & 1 << 5) == 0;

    oldBits = newBits;
  }

#ifdef IS_AVR
  ISR(PCINT2_vect)
  {
    processInputs();
  }
#endif

#ifdef IS_STM

#endif
} // namespace Input

#endif

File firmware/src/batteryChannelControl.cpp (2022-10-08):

#include "batteryChannelControl.h"
#include "utils.h"
#include "display.h"

#define UPDATE_DELAY_MS 100
#define ALPHA_1S

void BatteryChannelControl::loop()
{
    hal.loop();
    instantMs_t now = utils::now();
    if (now > nextUpdate)
    {
        nextUpdate = now + UPDATE_DELAY_MS;

        // read back the voltage
        measuredVoltageRaw = hal.readVoltage();
        measuredVoltage = measuredVoltageRaw * config().adcRefVoltage / 0xFFFF;

        // calculate the effective current flowing
        {
            float roundedOutputCurrent = ((int32_t)outputCurrentPWM - config().zeroOutputPwm(measuredVoltage)) / config().pwmFactor;

            // calculate the required voltage on the other side of the shunt
            float shuntInput = measuredVoltage + roundedOutputCurrent * config().shuntResistance;

            // limit the voltage to 0..inputVoltage
            shuntInput = max(0.f, min(eeprom::data.minInputVoltage, shuntInput));

            // calculate the current with the limited input voltage
            effectiveCurrent = (shuntInput - measuredVoltage) / config().shuntResistance;
            effectiveCurrent1s = alpha1s * effectiveCurrent + (1 - alpha1s) * effectiveCurrent1s;
            effectiveCurrent5s = alpha5s * effectiveCurrent + (1 - alpha5s) * effectiveCurrent5s;
        }
        // calculate the battery voltage
        batteryVoltage = measuredVoltage - effectiveCurrent * config().connectionResistance;

        batteryVoltage1s = alpha1s * batteryVoltage + (1 - alpha1s) * batteryVoltage1s;
    }

    if (now > nextControlUpdate)
    {
        float voltageDiffToLimit = abs(batteryVoltage - limitVoltage);
        if (voltageDiffToLimit < 0.2)
            nextControlUpdate = now + 800; // reduce control loop speed when close to the limit
        else if (voltageDiffToLimit < 0.5)
            nextControlUpdate = now + 400; // reduce control loop speed when close to the limit
        else
            nextControlUpdate = now + 200;

#if IS_FRAMEWORK_NATIVE
        nextControlUpdate = now + 100;
#endif

        // adjst the target current based on the mode
        bool increaseCurrent = false;
        switch (mode)
        {
        case BatteryChannelControl::Mode::IDLE:
            stepSize = 1;
            outputCurrentPWM = zeroOutputCurrentPWM();
            hal.setOutputPWM(outputCurrentPWM);
            return; // exit method, we're done

        case BatteryChannelControl::Mode::DIRECT_PWM:
            stepSize = 1;
            outputCurrentPWM = targetDirectPWM;
            hal.setOutputPWM(outputCurrentPWM);
            return; // exit method, we're done

        case Mode::SOURCE:
        {
            if (effectiveCurrent < 0)
                increaseCurrent = true;
            else if (batteryVoltage > limitVoltage)
                increaseCurrent = false;
            else
            {
                float i;
                switch (target)
                {
                case Target::CURRENT:
                {
                    i = targetCurrent;
                }
                break;

                case Target::RESISTANCE:
                {
                    i = (config().resistorSourceRefVoltage - batteryVoltage) / targetResistance;
                }
                break;
                case Target::POWER:
                    i = targetPower / batteryVoltage;
                    break;
                }

                if (effectiveCurrent < i)
                    increaseCurrent = true;
                else
                    increaseCurrent = false;
            }
        }
        break;
        case Mode::SINK:
        {
            if (effectiveCurrent > 0)
                increaseCurrent = false;
            else if (batteryVoltage < limitVoltage)
                increaseCurrent = true;
            else
            {
                float i;
                switch (target)
                {
                case Target::CURRENT:
                {
                    i = targetCurrent;
                }
                break;

                case Target::RESISTANCE:
                {
                    i = (0 - batteryVoltage) / targetResistance;
                }
                break;
                case Target::POWER:
                    i = -targetPower / (config().resistorSourceRefVoltage - batteryVoltage);
                    break;
                }

                if (effectiveCurrent < i)
                    increaseCurrent = true;
                else
                    increaseCurrent = false;
            }
        }
        break;
        }

        // adjust output current using exponential search
        if (increaseCurrent)
        {
            if (lastStepWasIncrease)
                stepSize *= 1.41;
            else
                stepSize /= 2;
            stepSize = max(stepSize, 1.f); // by one step minimum
            int32_t tmp = outputCurrentPWM + stepSize;
            if (tmp >= BatteryChannelHal::MAX_PWM)
                outputCurrentPWM = BatteryChannelHal::MAX_PWM;
            else
                outputCurrentPWM = tmp;
        }
        else
        {
            if (lastStepWasIncrease)
                stepSize /= 2;
            else
                stepSize *= 1.41;
            stepSize = max(stepSize, 1.f); // by one step minimum
            int32_t tmp = outputCurrentPWM - stepSize;
            if (tmp < 0)
                outputCurrentPWM = 0;
            else
                outputCurrentPWM = tmp;
        }
        lastStepWasIncrease = increaseCurrent;

        // limit step size
        if (stepSize > BatteryChannelHal::MAX_PWM / 32)
            stepSize = BatteryChannelHal::MAX_PWM / 32;

        // make sure no current is sunk in source mode and vice versa
        uint16_t zeroPwm = zeroOutputCurrentPWM();
        if ((mode == Mode::SOURCE && outputCurrentPWM < zeroPwm) || (mode == Mode::SINK && outputCurrentPWM > zeroPwm))
        {
            outputCurrentPWM = zeroPwm;
            stepSize = 1;
        }
        hal.setOutputPWM(outputCurrentPWM);
    }
}

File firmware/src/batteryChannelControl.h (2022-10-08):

#ifndef BATTERY_CHANNEL_CONTROL_H
#define BATTERY_CHANNEL_CONTROL_H

#include "batteryChannelHal.h"
#include "utils.h"
#include "config.h"
#include "eeprom.h"
#include "log.h"

#if IS_FRAMEWORK_NATIVE
#include <stdio.h>
#include <string.h>
#include <stdlib.h>
#include <ncurses.h>
#include <math.h>
#endif

/**
 * Controls a battery channel via the BatteryChannelHAL. Provides
 * the abstraction of a constant current/constant voltage source/sink.
 * */
class BatteryChannelControl
{
    instantMs_t nextUpdate = 0;
    instantMs_t nextControlUpdate = 0;

    bool lastStepWasIncrease = false;
    float stepSize = 0;

    uint16_t zeroOutputCurrentPWM()
    {
        return BatteryChannelHal::MAX_PWM / 2;
    }

    static constexpr instantMs_t updateDelayMs = 100;
    static constexpr float alpha1s = 1 - exp(-updateDelayMs / 1000.);
    static constexpr float alpha5s = 1 - exp(-updateDelayMs / 5000.);

public:
    enum class Mode
    {
        IDLE,
        SOURCE,
        SINK,
        DIRECT_PWM
    };

    enum class Target
    {
        CURRENT,
        RESISTANCE,
        POWER,
    };

    Mode mode = Mode::IDLE;
    Target target = Target::CURRENT;

    // voltage at the battery, adjusted with the current and the known contact resistance
    float batteryVoltage = 0;
    float batteryVoltage1s = 0;

    // voltage measured in the tester
    float measuredVoltage = 0;
    uint16_t measuredVoltageRaw = 0;

    float effectiveCurrent = 0;
    uint16_t outputCurrentPWM = 0;
    float effectiveCurrent1s = 0;
    float effectiveCurrent5s = 0;

    float targetCurrent = 0;    // amps
    float targetResistance = 0; // ohm
    float targetPower = 0;      // watts

    uint16_t targetDirectPWM = 0;

    float limitVoltage = 0;

    BatteryChannelHal hal;

    void init(int channel)
    {
        hal.init_inst(channel);
    }

    eeprom::ChannelConfig &config()
    {
        return eeprom::data.channelConfig[hal.channel];
    }

    void idle()
    {
        this->mode = BatteryChannelControl::Mode::IDLE;
    }

    void loop();

#if IS_FRAMEWORK_NATIVE
    void print(WINDOW *w)
    {
        wprintw(w, "control mode: ");
        switch (mode)
        {
        case BatteryChannelControl::Mode::SOURCE:
            wprintw(w, "SOURCE");
            break;
        case BatteryChannelControl::Mode::SINK:
            wprintw(w, "SINK");
            break;
        case BatteryChannelControl::Mode::IDLE:
            wprintw(w, "IDLE");
            break;
        }

        if (mode != BatteryChannelControl::Mode::IDLE)
        {
            wprintw(w, " target: ");
            switch (target)
            {
            case BatteryChannelControl::Target::CURRENT:
                wprintw(w, "CURRENT %lf", targetCurrent);
                break;
            case BatteryChannelControl::Target::RESISTANCE:
                wprintw(w, "RESISTANCE %f", targetResistance);
                break;
            case BatteryChannelControl::Target::POWER:
                wprintw(w, "POWER %f", targetPower);
                break;
            }
        }

        wprintw(w, " limitVoltage: %f stepSize: %f pwm: %i", limitVoltage, stepSize, outputCurrentPWM);
        wprintw(w, " uMeas: %f uBat: %f zeroPWM: %i", measuredVoltage, batteryVoltage, config().zeroOutputPwm(measuredVoltage));
        wprintw(w, " HAL: uInt: %f, uBat %f, capacity: %f pwm: %i current: %f\n",
                hal.voltage, hal.uBat(), hal.capacity, hal.outputPWM, hal.outputCurrent);
        wrefresh(w);
    }
#endif
};

#endif

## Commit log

2022-08-10 switch to ncurses
2022-08-13 switch to cc controlled hardware
2022-08-21 improve power control
2022-08-29 add holder scad
    [BatteryHolder.scad]
2022-08-31 work on holder
    [BatteryHolder.scad]
2022-09-01 add direct PWM mode
2022-09-10 add kicad
    [channel.kicad_pcb, channel.kicad_sch, controller.kicad_pcb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]
2022-09-13 work on kicad
    [channel.kicad_pcb, channel.kicad_sch, controller.kicad_pcb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]
2022-09-16 rework PINS, get SD Card working
    [channel.kicad_pcb, channel.kicad_sch, controller.kicad_pcb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]
2022-09-23 fix flash, fix frequency compensation
    [BatteryHolder.scad, channel.kicad_pcb, channel.kicad_sch]
2022-09-23 add qucs
    [simple.sch]
2022-09-27 add resistor matching
    [channel.kicad_pcb, channel.kicad_sch, simple.sch]
2022-09-29 move mosfets
    [channel.kicad_pcb, channel.kicad_sch]
2022-10-02 fix calculation bug, EEPROM reset confirmation question
    [batteryChannel.cpp, controller.cpp, eeprom.h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]
2022-10-02 implement Test charger mode
2022-10-08 work on pulse charge/discharge, combined board
    [channel2.kicad_pcb, channel2.kicad_sch, combined.kicad_pcb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]
2022-10-15 fix resistor values around transistor
    [channel2.kicad_sch, controller2.kicad_sch, simple.sch]
2022-10-18 minor schematic cleanups, improve opamp compensation
    [channel2.kicad_pcb, channel2.kicad_sch, combined.kicad_pcb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]
